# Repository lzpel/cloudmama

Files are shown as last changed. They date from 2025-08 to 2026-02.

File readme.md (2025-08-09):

# cloudmama

機械学習で生活習慣改善を支援するAIカメラ。
一人暮らしの大学生・社会人の生活を指導する目でありたい。

Maker Faire Tokyo 2023 (10/14-15 @ビッグサイト) に出展予定。
5月11日（木）～出展作品の受付が始まるので準備を進めている。

## 紹介動画と紹介記事

[動画: Maker Faire Tokyo 2023 出展作品紹介 規則正しい生活を支援するAIカメラ cloudmama](https://vimeo.com/803534490)

[記事: ステイホームで乱れた生活習慣を機械学習を使って改善する話 #kuac2020](https://qiita.com/lzpel/items/e25633684128cebec6b8)

## 作り方

1. [3dmodel/package.stl](./3dmodel/package.stl)を3Dプリンターで印刷します
2. [PCB/LZP32-SPEAKER_(最新版)](./PCB)をPCB製造業者（例えばSeeeds Fusion, PCBWAY）などで製造してもらいます。
    - BOMに従い部品も実装してください
3. スピーカー（F02607H0）（[秋月電子](https://akizukidenshi.com/catalog/g/gP-10366/)）を購入してください
    - これでなくとも大抵の8ohmスピーカーに対応しています、別のスピーカーを用いる場合は自分で外装を設計してください。
4. スピーカーの+/-を発注した基盤の+/-にスクリューターミナルを用いて接続してください。
6. USB給電すれば動作します。
7. Wifiから設定画面に接続します。
    - TODO: 以下完成させる、プロトタイピングとしては動くが配布できる状態ではない

## 開発ノウハウ

- esp-idf5.0のwindows版 をインストールして組み込みプログラミングを行う
  - docker image版の開発環境は仮想環境からUSBを経由してボードに書き込めないので使えない
- スピーカーと接続する screw terminal の部品選定について
  - KF350-3.5-2P  採用
  - DB125-3.5-2P-GN-S　　不採用　在庫が少ないので依存するのは良くない
- Fusion360による基板設計での頻出問題と解決法
  - 部品の3Dモデルが反映されない
    - 3Dモデルにstlを使っている->体積を持たないので使えません（警告マークが出ているはずです）STEPファイルを使いましょう
    - STEPファイルを読み込めない->メッシュとしては読み込めません->Teamの一ファイルとしてアップロードし、それを外部コンポーネントとして挿入しましょう（ドラッグアンドドロップ）
    - 3Dモデルが更新されていない->基盤デザインで「ライブラリからデザインを更新」をクリック、「デザインで使用されている全てのライブラリからデザインを更新」ボタンは効果がない->3DPCBにプッシュ

## License

MIT Copyright 2020 lzpel

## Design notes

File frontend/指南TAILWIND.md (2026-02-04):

# tailwindcssの導入(v4)

https://tailwindcss.com/docs/installation/using-postcss

npm install @tailwindcss/postcss tailwindcss # postcss はnextjsに同封されているので不要

# postcss.config.mjsの作成

```postcss.config.mjs
const config = {
  plugins: {
    "@tailwindcss/postcss": {},
  },
};

export default config;
```

# paletteのclassを定義

```
/** @type {import('tailwindcss').Config} */
// material ui風のpaletteを導入
module.exports = {
	content: [
		"./app/**/*.{js,ts,jsx,tsx,mdx}",
		"./pages/**/*.{js,ts,jsx,tsx,mdx}",
		"./components/**/*.{js,ts,jsx,tsx,mdx}",
		"./src/**/*.{js,ts,jsx,tsx,mdx}",
	],
	theme: {
		extend: {
			/**
			 * 重要:
			 * - CSS変数は `R G B` (例: "25 118 210") の形式で持つ想定
			 * - Tailwind側は `rgb(var(--...)/<alpha-value>)` を参照
			 *
			 * 例: --palette-primary-main: 25 118 210;
			 */
			colors: {
				// ===== Tone (primary/secondary/...) =====
				primary: {
					main: "rgb(var(--palette-primary-main) / <alpha-value>)",
					contrast: "rgb(var(--palette-primary-contrastText) / <alpha-value>)",
					light: "rgb(var(--palette-primary-light) / <alpha-value>)",
					dark: "rgb(var(--palette-primary-dark) / <alpha-value>)",
				},
				secondary: {
					main: "rgb(var(--palette-secondary-main) / <alpha-value>)",
					contrast: "rgb(var(--palette-secondary-contrastText) / <alpha-value>)",
					light: "rgb(var(--palette-secondary-light) / <alpha-value>)",
					dark: "rgb(var(--palette-secondary-dark) / <alpha-value>)",
				},
				error: {
					main: "rgb(var(--palette-error-main) / <alpha-value>)",
					contrast: "rgb(var(--palette-error-contrastText) / <alpha-value>)",
					light: "rgb(var(--palette-error-light) / <alpha-value>)",
					dark: "rgb(var(--palette-error-dark) / <alpha-value>)",
				},
				warning: {
					main: "rgb(var(--palette-warning-main) / <alpha-value>)",
					contrast: "rgb(var(--palette-warning-contrastText) / <alpha-value>)",
					light: "rgb(var(--palette-warning-light) / <alpha-value>)",
					dark: "rgb(var(--palette-warning-dark) / <alpha-value>)",
				},
				info: {
					main: "rgb(var(--palette-info-main) / <alpha-value>)",
					contrast: "rgb(var(--palette-info-contrastText) / <alpha-value>)",
					light: "rgb(var(--palette-info-light) / <alpha-value>)",
					dark: "rgb(var(--palette-info-dark) / <alpha-value>)",
				},
				success: {
					main: "rgb(var(--palette-success-main) / <alpha-value>)",
					contrast: "rgb(var(--palette-success-contrastText) / <alpha-value>)",
					light: "rgb(var(--palette-success-light) / <alpha-value>)",
					dark: "rgb(var(--palette-success-dark) / <alpha-value>)",
				},

				// ===== text/background/divider/action =====
				text: {
					primary: "rgb(var(--palette-text-primary) / <alpha-value>)",
					secondary: "rgb(var(--palette-text-secondary) / <alpha-value>)",
					disabled: "rgb(var(--palette-text-disabled) / <alpha-value>)",
				},
				background: {
					default: "rgb(var(--palette-background-default) / <alpha-value>)",
					paper: "rgb(var(--palette-background-paper) / <alpha-value>)",
				},
				divider: "rgb(var(--palette-divider) / <alpha-value>)",
				action: {
					hover: "rgb(var(--palette-action-hover) / <alpha-value>)",
					selected: "rgb(var(--palette-action-selected) / <alpha-value>)",
					disabled: "rgb(var(--palette-action-disabled) / <alpha-value>)",
					disabledBackground:
						"rgb(var(--palette-action-disabledBackground) / <alpha-value>)",
					focus: "rgb(var(--palette-action-focus) / <alpha-value>)",
				},
			},
		},
	},
	darkMode: ["class"], // palette.mode と合わせるなら class 運用が安定
	plugins: [],
};
```

## フロントエンド部品の作り方

stateless_ui/以下にフロントエンド部品を配置する

```FormControls.tsx
//- 一行入力、ラジオボタン、コントロールをchildrenに入れてラベルを付ける部品をexport function
//全体ルール：
//- UI部品はexport function/export default functionで構築、constに関数を入れるのは禁止
//- ... function ... (props: ...){ props.要素 }のように引数を宣言する。... function ... ({...}:型)のように引数を宣言しない。
//- イベントハンドラや値は必要なら親から注入できるようにpropsの型を定義
//- 色はハードコーディングせずこれを使用⇒frontend\tailwind.config.js
//stateless_ui/以下のTsxに適用するルール
//- 外観を期待しており動作を期待していないのでuseState/useEffect/useRefなどを禁止
//- export function Example()を定義して、このファイルで定義したUI部品の一覧を確認できるようにする。app/sandbox/page.tsxにこのファイルの<このファイル.Example/>を配置する。
//以上の共通ルールは保持、共通ルール以降に内容を実装して
```

AIに指示
> frontend\stateless_ui\FormControls.tsxの共通ルール以降に内容を実装して

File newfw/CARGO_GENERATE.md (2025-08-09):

$ cargo generate esp-rs/esp-idf-template
⚠️   Favorite `esp-rs/esp-idf-template` not found in config, using it as a git repository: https://github.com/esp-rs/esp-idf-template.git
✔ 🤷   Which template should be expanded? · cargo
🤷   Project Name: newfw
🔧   Destination: C:\cloudmama\newfw\newfw ...
🔧   project-name: newfw ...
🔧   Generating template ...
✔ 🤷   Which MCU to target? · esp32
✔ 🤷   Configure advanced template options? · false

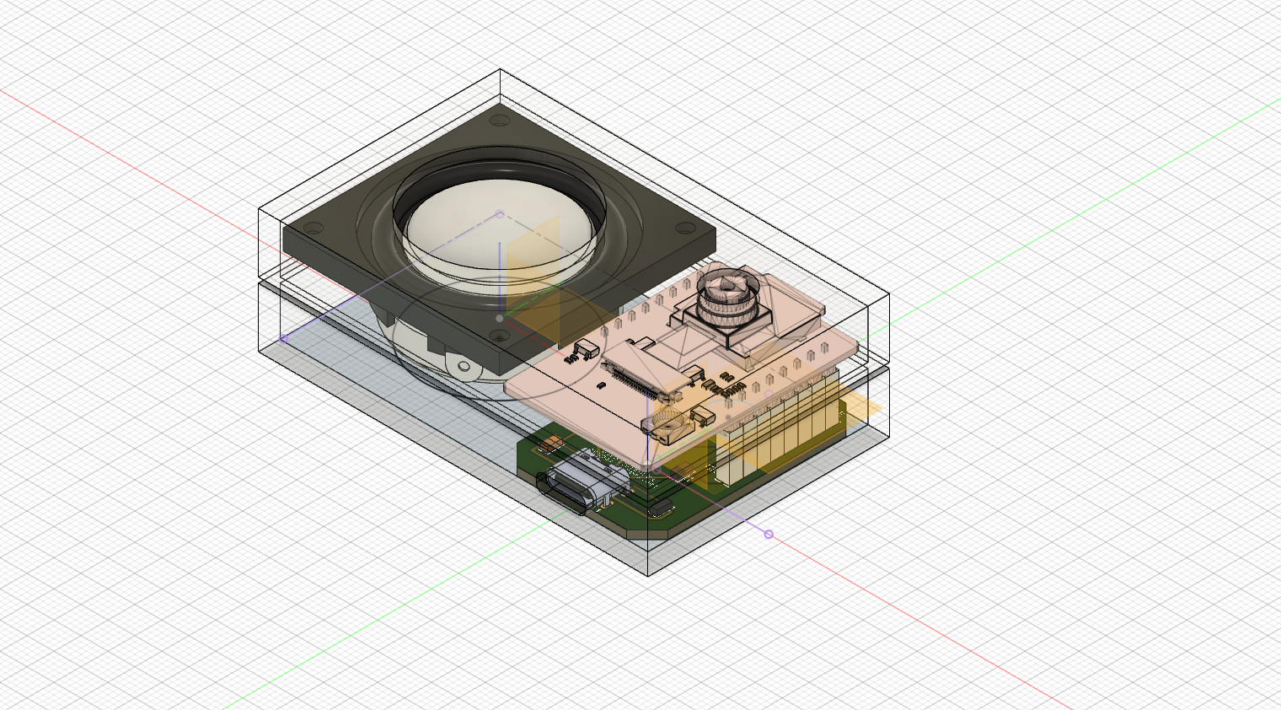
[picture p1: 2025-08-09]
figures/camera v11.png

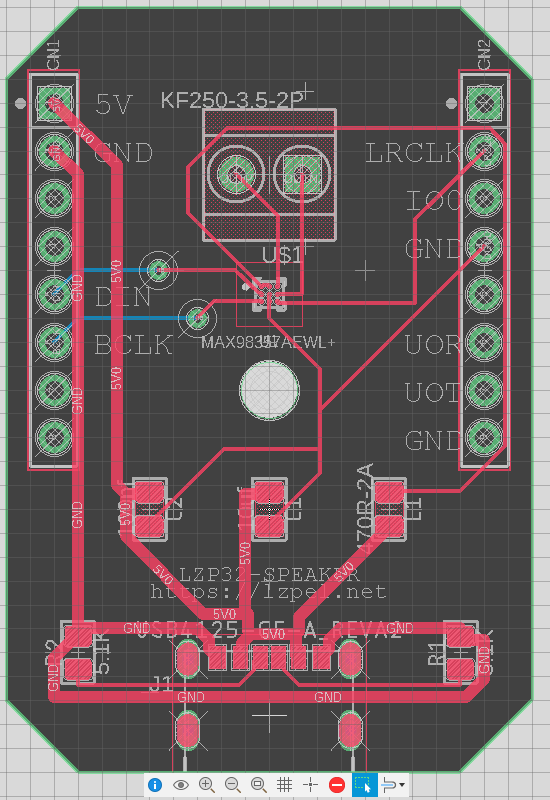
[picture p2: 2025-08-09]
figures/pcb.png

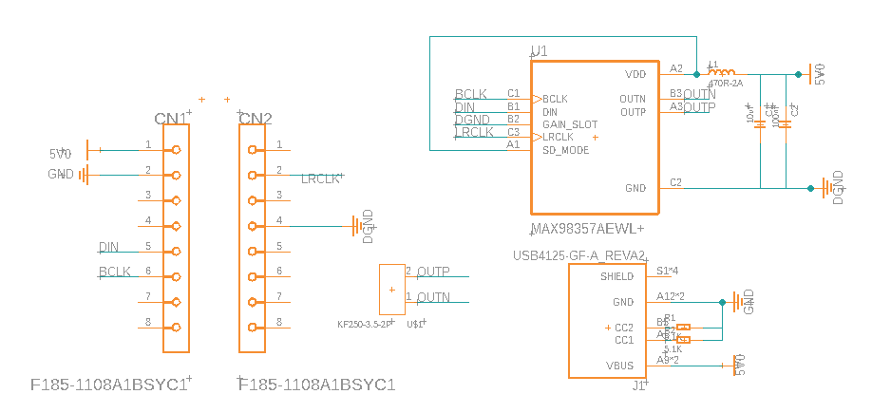
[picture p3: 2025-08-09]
figures/scheme.png

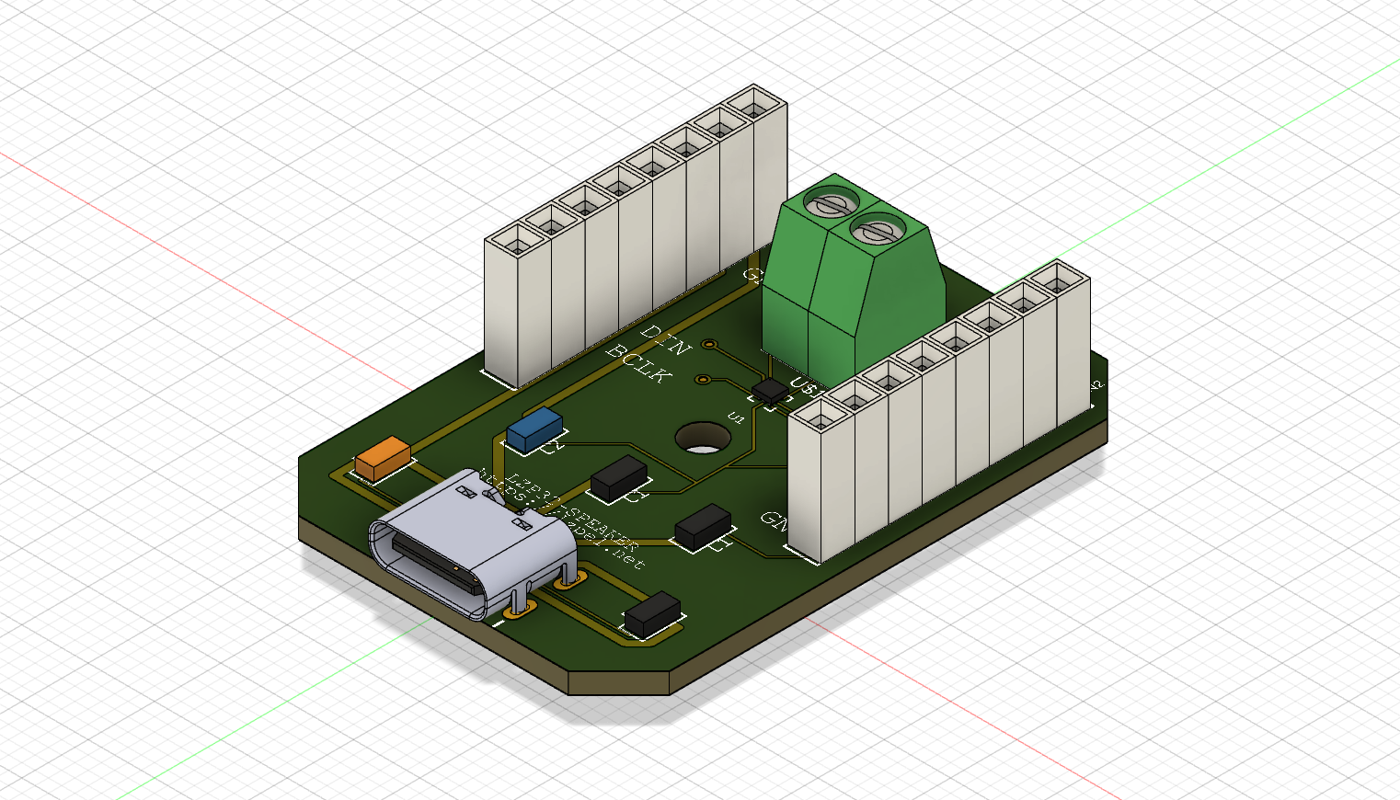
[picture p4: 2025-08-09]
figures/LZP32-SPEAKER v22.png

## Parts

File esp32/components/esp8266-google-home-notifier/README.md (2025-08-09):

# esp8266-google-home-notifier
Send notifications to Google Home from esp8266.

This library depends on Google Translate Service.

[This](https://qiita.com/horihiro/items/4ab0edf415916a2cd542) is the Japanese document on [Qiita.com](https://qiita.com/);

## Install
This library can be installed from the Library Manager on Arduino IDE

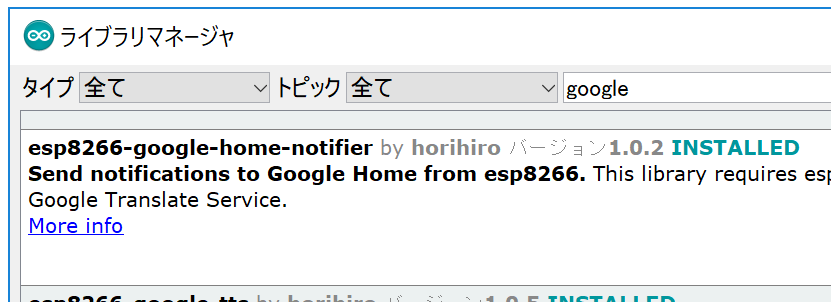
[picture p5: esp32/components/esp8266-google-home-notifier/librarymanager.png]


## Requirement
- Arduino board 
  - esp8266
  - esp32<br>
    (note: 1.0.2 and later, and 1.0.4 requires [83810fa](https://github.com/espressif/arduino-esp32/tree/83810fa1563f77145272583e36dfb076d3a92018)  or later of [arduino-esp32](https://github.com/espressif/arduino-esp32))
- [esp8266-google-tts](https://github.com/horihiro/esp8266-google-tts) <br>
  [download from Library Manager](https://github.com/horihiro/esp8266-google-tts/blob/master/README.md#install) of Arduino IDE

- (only for ver 1.0.1 and earlier) Latest ESP8266mDNS
  - download [ESP8266mDNS.cpp](https://github.com/mblythe86/Arduino/blob/master/libraries/ESP8266mDNS/ESP8266mDNS.cpp)/[.h](https://github.com/mblythe86/Arduino/blob/master/libraries/ESP8266mDNS/ESP8266mDNS.h) to  `$LIBRARIES_DIR/esp8266-google-home-notifier/src/` and restart Arduino IDE, like below structure. <br>
  ```
  $LIBRARIES_DIR
    └── esp8266-google-home-notifier/
        ├── LICENSE
        ├── README.md
        :
        └── src/
            ├── ESP8266mDNS.cpp  # <- additional file
            ├── ESP8266mDNS.h    # <- additional file
            :
            ├── esp8266-google-home-notifier.cpp
            └── esp8266-google-home-notifier.h
  ```
  or
  - ~~use [Arduino Core for ESP8266](https://github.com/esp8266/Arduino/) **2.5.0**, which will [merge ESP8266mDNS.cpp/.h](https://github.com/esp8266/Arduino/pull/3107), or later.~~<br>
  -> The PR wasn't merged, so MDNS handling in this library should be fix under ESP8266 cor 2.5.0 or later.

## Usage
### Simple for esp8266/32
```
#ifdef ARDUINO_ARCH_ESP8266
#include <ESP8266WiFi.h>
#endif

#ifdef ARDUINO_ARCH_ESP32
#include <WiFi.h>
#endif
#include <esp8266-google-home-notifier.h>

const char* ssid     = "<REPLASE_YOUR_WIFI_SSID>";
const char* password = "<REPLASE_YOUR_WIFI_PASSWORD>";

GoogleHomeNotifier ghn;

void setup() {
  // put your setup code here, to run once:
  Serial.begin(115200);
  Serial.println("");
  Serial.print("connecting to Wi-Fi");
  WiFi.mode(WIFI_STA);
  WiFi.begin(ssid, password);

  while (WiFi.status() != WL_CONNECTED) {
    delay(250);
    Serial.print(".");
  }
  Serial.println("");
  Serial.println("connected.");
  Serial.print("IP address: ");
  Serial.println(WiFi.localIP());  //Print the local IP
  
  const char displayName[] = "Family Room";

  Serial.println("connecting to Google Home...");
  if (ghn.device(displayName, "en") != true) {
    Serial.println(ghn.getLastError());
    return;
  }
  Serial.print("found Google Home(");
  Serial.print(ghn.getIPAddress());
  Serial.print(":");
  Serial.print(ghn.getPort());
  Serial.println(")");
  
  if (ghn.notify("Hello, World!") != true) {
    Serial.println(ghn.getLastError());
    return;
  }
  Serial.println("Done.");
}

void loop() {
  // put your main code here, to run repeatedly:

}
```

### Notification Server for esp8266
```
#include <ESP8266WiFi.h>
#include <ESP8266WebServer.h>
#include <esp8266-google-home-notifier.h>

const char* ssid     = "<REPLASE_YOUR_WIFI_SSID>";
const char* password = "<REPLASE_YOUR_WIFI_PASSWORD>";

ESP8266WebServer server(80);
GoogleHomeNotifier ghn;

void setup() {
  // put your setup code here, to run once:
  Serial.begin(115200);
  Serial.println("");
  Serial.print("connecting to Wi-Fi");
  WiFi.mode(WIFI_STA);
  WiFi.begin(ssid, password);

  while (WiFi.status() != WL_CONNECTED) {
    delay(250);
    Serial.print(".");
  }
  Serial.println("");
  Serial.println("connected.");
  Serial.print("IP address: ");
  Serial.println(WiFi.localIP());  //Print the local IP
  
  const char displayName[] = "Family Room";

  Serial.println("connecting to Google Home...");
  if (ghn.device(displayName, "en") != true) {
    Serial.println(ghn.getLastError());
    return;
  }
  Serial.print("found Google Home(");
  Serial.print(ghn.getIPAddress());
  Serial.print(":");
  Serial.print(ghn.getPort());
  Serial.println(")");
  
  server.on("/speech", handleSpeechPath);
  server.on("/", handleRootPath);
  server.begin();
 }

void handleSpeechPath() {
  String phrase = server.arg("phrase");
  if (phrase == "") {
    server.send(401, "text / plain", "query 'phrase' is not found");
    return;
  }
  if (ghn.notify(phrase.c_str()) != true) {
    Serial.println(ghn.getLastError());
    server.send(500, "text / plain", ghn.getLastError());
    return;
  }
  server.send(200, "text / plain", "OK");
}

void handleRootPath() {
  server.send(200, "text/html", "<html><head></head><body><input type=\"text\"><button>speech</button><script>var d = document;d.querySelector('button').addEventListener('click',function(){xhr = new XMLHttpRequest();xhr.open('GET','/speech?phrase='+encodeURIComponent(d.querySelector('input').value));xhr.send();});</script></body></html>");
}

void loop() {
  // put your main code here, to run repeatedly:
  server.handleClient();
}
```

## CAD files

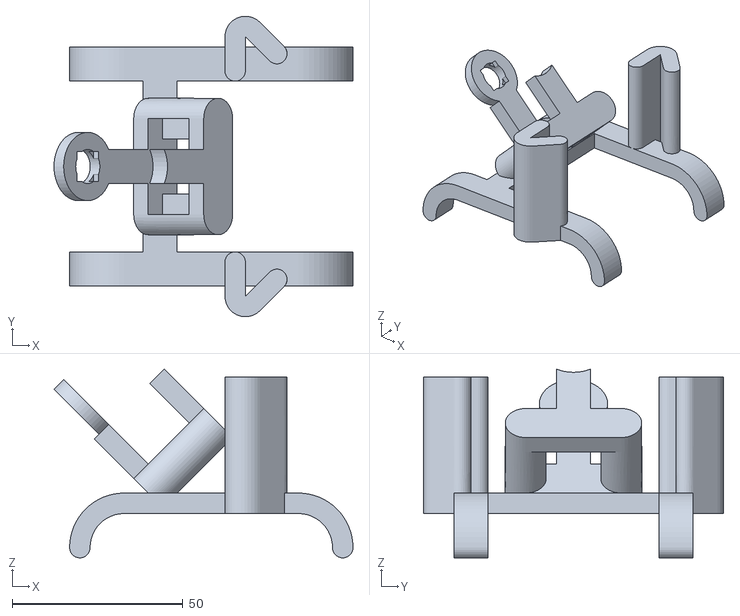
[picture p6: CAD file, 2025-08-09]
3dmodel/package.stl
87.6 x 88.0 x 55.3

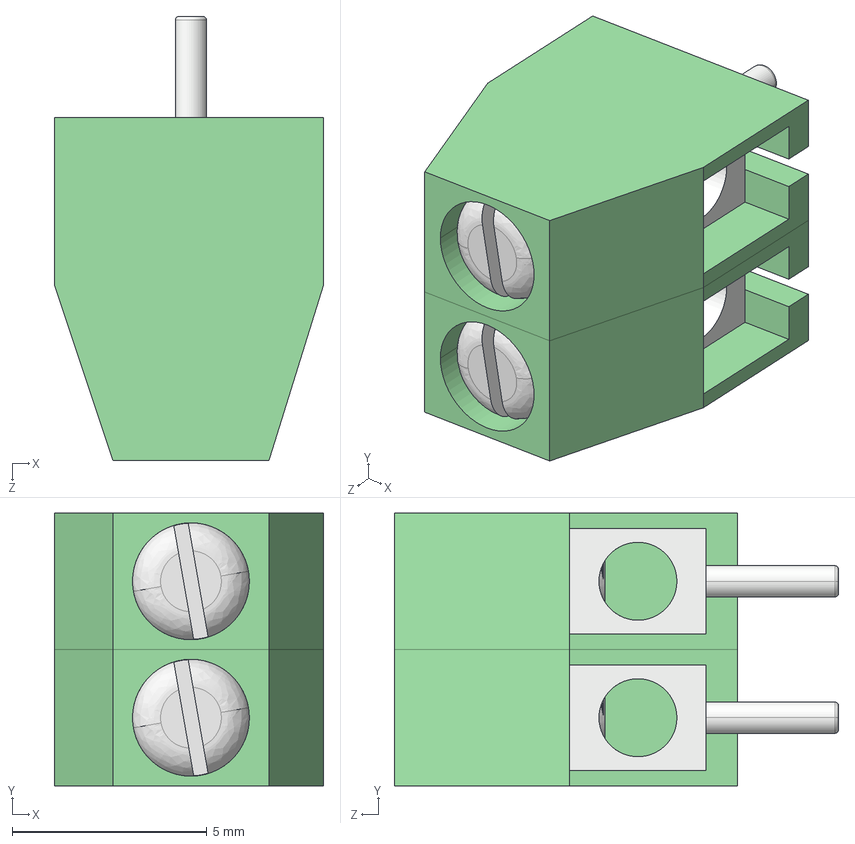
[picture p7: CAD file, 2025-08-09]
PCB/component/KF350-3.5-2P.STEP
6.90 x 7.00 x 11.4 mm
KF850 Body x 2
KF850 PIN x 2
M2 Screw_91200A100 x 2

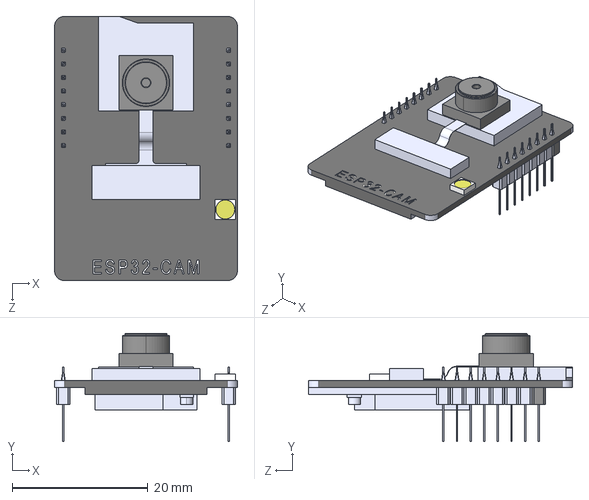
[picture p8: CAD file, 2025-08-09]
PCB/component/ESP32-CAM.STEP
27.0 x 16.0 x 39.0 mm

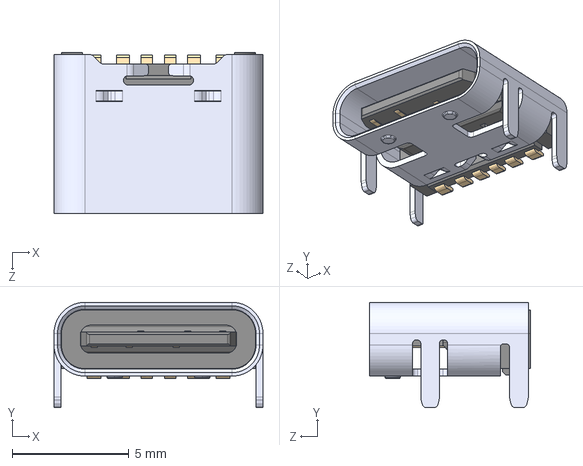
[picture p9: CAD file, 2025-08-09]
PCB/component/USB4125-GF-A.STEP
8.94 x 4.51 x 6.90 mm

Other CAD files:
PCB/component/LZP32-SPEAKER v43.f3z

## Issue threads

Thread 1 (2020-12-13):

計画

lzpel, 2020-12-13:
## ESP32にMAX98360を接続

- MAX98357を接続
  - 物理的に接続
    - はんだごてを購入
  - 音声を送信
    - https://jiwashin.blogspot.com/2017/09/esp32i2s.html
  - mp3からデコード

lzpel, 2020-12-20:
## ケース
たかちの箱 TW5-3-10B 280円
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

lzpel, 2021-11-09:
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
20211109 18:32 こんな基盤を作る

lzpel, 2021-11-16:
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

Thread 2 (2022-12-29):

基盤に給電できない。ブレッドボードで確認する。

lzpel, 2022-12-29:
必要なのは定評のあるテスター
USB-Cモジュール及びUSBの規格に対応する抵抗
--- ここまででUSB給電のできるはず ---

（持ってる）MAX98357モジュール
（持ってる）スピーカー
--- ここまでで音がならせるはず---

lzpel, 2022-12-30:
バイパスをはんだ付けしてもLEDが光らないので5VとGNDがショートしているとしか考えられない

lzpel, 2022-12-30:
左に傾けて基盤に押し込むとLEDが光る。
右側の何かが導通すると動かなくなる。GNDをハイインピーダンスに保つべきだったのかも

lzpel, 2022-12-30:
あたりだった、このような基盤にも対応して右側GNDをハイインピーダンスに保った回路に書き直す
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

lzpel, 2023-01-06:
基盤を改良して解決

Closed 2023-01-06.

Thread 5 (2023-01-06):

100hz正弦波を鳴らすとノイズが乗る

lzpel, 2023-01-06:
気づいたこと
- コンセントから引いたUSBもパソコンから引いたUSBも同じようなノイズが乗る
- 400hzなら多少マシ

- 可能性1
- アンプのパワー>スピーカーのパワー
- SC400308-1は8 Ohms 汎用 スピーカ 2 W 200 Hz ~ 20 kHz 上 長方形

lzpel, 2023-01-12:
高級なスピーカーでもノイズは消えなかった

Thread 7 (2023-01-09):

Object Detectionを組み込む

lzpel, 2023-01-09:
random forest による実装

https://eloquentarduino.com/esp32-cam-image-recognition/

deep learning による実装

```
// This is a TensorFlow Lite model file that has been converted into a C data
// array using the tensorflow.lite.util.convert_bytes_to_c_source() function.
// This form is useful for compiling into a binary for devices that don't have a
// file system.
```

https://github.com/tanakamasayuki/Arduino_TensorFlowLite_ESP32/tree/master/examples/person_detection

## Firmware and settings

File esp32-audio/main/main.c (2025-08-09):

#include "sdkconfig.h"
#include "freertos/FreeRTOS.h"
#include "freertos/task.h"
#include "driver/i2s_std.h"
#include "driver/gpio.h"
#include <math.h>
#include <stdio.h>
// https://docs.espressif.com/projects/esp-idf/en/latest/esp32/api-reference/peripherals/i2s.html

i2s_chan_handle_t tx_handle;

/* Allocate a new tx channel and get the handle of this channel */
#define sample_rate 48000
#define wave_hz 400
int16_t samples[256];
int phase = 0;

signed read_wave(int16_t *p, signed size) {
    double sin_float;
    for (int i = 0; i < size; i++) {
        sin_float = sin(2 * 3.14159 * phase * wave_hz / sample_rate);
        p[i] = (0 + sin_float * 0.5) * (double) (65536 / 2);
        phase++;
    }
    return size;
}

void app_main(void) {
    // Setting the configurations, the slot configuration and clock configuration can be generated by the macros
    // These two helper macros is defined in 'i2s_std.h' which can only be used in STD mode.
    // They can help to specify the slot and clock configurations for initialization or updating
    i2s_std_config_t std_cfg = {
            .clk_cfg = I2S_STD_CLK_DEFAULT_CONFIG(sample_rate),
            .slot_cfg = I2S_STD_MSB_SLOT_DEFAULT_CONFIG(I2S_DATA_BIT_WIDTH_16BIT, I2S_SLOT_MODE_MONO),
            .gpio_cfg = {
                    .mclk = I2S_GPIO_UNUSED,
                    //基盤に合わせて変更
                    .bclk = GPIO_NUM_14,
                    .ws = GPIO_NUM_16,
                    .dout = GPIO_NUM_15,
                    .din = I2S_GPIO_UNUSED,
                    .invert_flags = {
                            .mclk_inv = false,
                            .bclk_inv = false,
                            .ws_inv = false,
                    },
            },
    };
    i2s_chan_config_t chan_cfg = I2S_CHANNEL_DEFAULT_CONFIG(I2S_NUM_AUTO, I2S_ROLE_MASTER);
    //chan_cfg.dma_desc_num = 3;
    //chan_cfg.dma_frame_num = sample_per_cycle;//dma_buffer_size = dma_frame_num * slot_num * slot_bit_width / 8
    printf("%d, %d, %d \n",
           (int) chan_cfg.dma_frame_num, (int) chan_cfg.dma_desc_num, (int) std_cfg.slot_cfg.slot_bit_width);
    i2s_new_channel(&chan_cfg, &tx_handle, NULL);
    i2s_channel_init_std_mode(tx_handle, &std_cfg);
    //i2s_event_callbacks_t callbacks={};
    //i2s_channel_register_event_callback(tx_handle, &callbacks, NULL);
    i2s_channel_enable(tx_handle);


    /* Before write data, start the tx channel first */
    for (unsigned i = 0; true; i++) {
        size_t tmp, ret, size;
        size = sizeof(samples) / sizeof(int16_t);
        size = read_wave(samples, size);
        ret = i2s_channel_write(tx_handle, samples, sizeof(int16_t) * size, &tmp, portMAX_DELAY);
        printf("%d %d %d %d\n", ret, tmp, ESP_OK, ESP_ERR_TIMEOUT);
        if (i % 100 == 0)vTaskDelay(1);
    }
    /* If the configurations of slot or clock need to be updated,
    * stop the channel first and then update it */
    // i2s_channel_disable(tx_handle);
    // std_cfg.slot_cfg.slot_mode = I2S_SLOT_MODE_MONO; // Default is stereo
    // i2s_channel_reconfig_std_slot(tx_handle, &std_cfg.slot_cfg);
    // std_cfg.clk_cfg.sample_rate_hz = 96000;
    // i2s_channel_reconfig_std_clock(tx_handle, &std_cfg.clk_cfg);

    /* Have to stop the channel before deleting it */
    i2s_channel_disable(tx_handle);
    /* If the handle is not needed any more, delete it to release the channel resources */
    i2s_del_channel(tx_handle);
}

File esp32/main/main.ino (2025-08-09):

//class WiFiClassとextern WiFiClass Wifiを宣言している。
#include <WiFi.h>

//https://github.com/espressif/arduino-esp32/tree/master/libraries/WebServer
//内部でWifi.hが提供するextern WiFiClass Wifiを利用している
#include <WebServer.h>
WebServer webserver;

//https://github.com/espressif/arduino-esp32/tree/master/libraries/HTTPClient
//HTTPクライアント
#include <HTTPClient.h>

//https://github.com/espressif/arduino-esp32/tree/master/libraries/WiFi
//class MDNSResponderとextern MDNSResponder MDNSを宣言している
//extern WiFiClass Wifiを使用
#include <ESPmDNS.h>

//https://github.com/horihiro/esp8266-google-home-notifier
#include <esp8266-google-home-notifier.h>

#include "camera.h"
#include "urlencode.h"

const int interval_seconds=60*10;

bool AutoConnect(const char* wifi, const char* pass) {
  // 10秒毎に接続していなければ再接続を試みる。秒数の根拠は以下。
  // https://github.com/espressif/arduino-esp32/blob/91b9fae111b8e601d8bdbcddf2dd430e0170706a/libraries/WiFi/src/WiFiSTA.cpp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
  static unsigned long time = 0;
  unsigned long now = millis(), status = WiFi.status();
  if ((time == 0 || (now - time) > 10000) && (time = now)) {
    if (status != WL_CONNECTED){
      Serial.printf("No connection, connecting %s:%s\n",wifi,pass);
      WiFi.begin(wifi, pass);
    }
  }
  return status == WL_CONNECTED;
}

void Scan(){
    Serial.println("scan start");

    // WiFi.scanNetworks will return the number of networks found
    int n = WiFi.scanNetworks();
    Serial.println("scan done");
    if (n == 0) {
        Serial.println("no networks found");
    } else {
        Serial.print(n);
        Serial.println(" networks found");
        for (int i = 0; i < n; ++i) {
            // Print SSID and RSSI for each network found
            Serial.print(i + 1);
            Serial.print(": ");
            Serial.print(WiFi.SSID(i));
            Serial.print(" (");
            Serial.print(WiFi.RSSI(i));
            Serial.print(")");
            Serial.println((WiFi.encryptionType(i) == WIFI_AUTH_OPEN)?" ":"*");
            delay(10);
        }
    }
    Serial.println("");

    // Wait a bit before scanning again
    delay(500);
}

String Request(const char* httpurl = "http://example.com/index.html", const char*postbuf = 0, const int postlen = 0) {
  String payload;
  int code;
  HTTPClient http;
  http.begin(httpurl); // start http connection and send HTTP header
  // http.begin("https://www.howsmyssl.com/a/check", ca); //HTTPS
  // ライブラリの方針でbegin系関数は設定だけ行いブロックしないのかも
  if (postbuf) {
    code = http.POST((uint8_t*)postbuf, postlen);
  } else {
    code = http.GET();
  }
  // httpCode will be negative on error
  if (code > 0) {
    // HTTP header has been send and Server response header has been handled
    // file found at server
    if (code == HTTP_CODE_OK) {
      payload = http.getString();
      Serial.printf("HTTP %d\n%s", code, payload.c_str());
    }
  }
  http.end();
  return payload;
}

void Speech(const char* deviceName, const char* url) {
  GoogleHomeNotifier ghn;
  Serial.println("connecting to Google Home...");
  if (ghn.device(deviceName, "jp")) {
    Serial.printf("found Google Home %s:%d\n", ghn.getIPAddress().toString().c_str(), ghn.getPort());
    if (ghn.play(url)) {
      Serial.printf("play %s\n", url);
      Serial.println(ghn.getLastError());
      return;
    }
  }
  Serial.println(ghn.getLastError());
}

void setup() {
  //シリアルモニタの同期周波数。PC側に以下の値を設定しないと文字化けする。
  Serial.begin(115200);
  //wifi等の状態を出力してくれるらしい。
  Serial.setDebugOutput(true);
  //シリアルモニタに出力
  Serial.println("HelloWorld");
  //Wifiの親機（アクセスポイント）かつ子機（ステーション）として振る舞うモードに設定。この処理が無くても動作するが明示的に書いた。
  WiFi.mode(WIFI_AP_STA);
  //アクセスポイントのパスワードは8文字以上に設定しないと失敗する
  WiFi.softAP("camerawifi", "camerapass");
  //ipアドレスにmdnsを設定。Wifi.modeに関わらない。
  if (MDNS.begin("cloudmama"))Serial.println("http://cloudmama.local/");
  //WifiAP確認
  Scan();
  //カメラ設定
  CameraInit();
  //ウェブサーバーを始める。Wifi.modeに関わらない。
  webserver.begin(80);
  //無名関数でレスポンスを作る
  webserver.on("/", []() {
    webserver.send(200, "text/html",
                   "<html>"
                   "<head></head>"
                   "<body>"
                   "<h1>Hello World</h1>"
                   "</body>"
                   "</html>"
                  );
  });
  webserver.on("/redirect", []() {
    webserver.sendHeader("Location", "/");
    webserver.sendHeader("Cache-Control", "no-cache");
    webserver.send(301);
  });
  webserver.on("/httpget", []() {
    //HTTPで取得した内容を直接表示
    //最後に/をつけないと404になった。
    webserver.send(200, "text/html", Request("http://lzpel.net/"));
  });
}
void loop() {
  static unsigned long time = 0;
  unsigned long now = millis();
  if (AutoConnect("SPWH_H33_5DCC29", "jmqfe8nqtafiny4")) {
    if ((time == 0 || (now - time) > 1000 * interval_seconds) && (time = now)) {
      String url("http://cloudmama.appspot.com/speech?i=");
      if(false){
        CameraOpen();
        url.concat(urlEncode(Request("http://cloudmama.appspot.com/image", CameraBuf(), CameraLen()).c_str()));
        CameraClose();
      }
      if(true){
        Speech("303", "http://cloudmama.appspot.com/speech");
      }
    }
  }
  webserver.handleClient();
}
